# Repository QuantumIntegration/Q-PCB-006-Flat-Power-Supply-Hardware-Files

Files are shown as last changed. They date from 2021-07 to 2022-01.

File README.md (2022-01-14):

# Quantum DIY Kit Hardware Files - Flat Power Supply
## Introduction

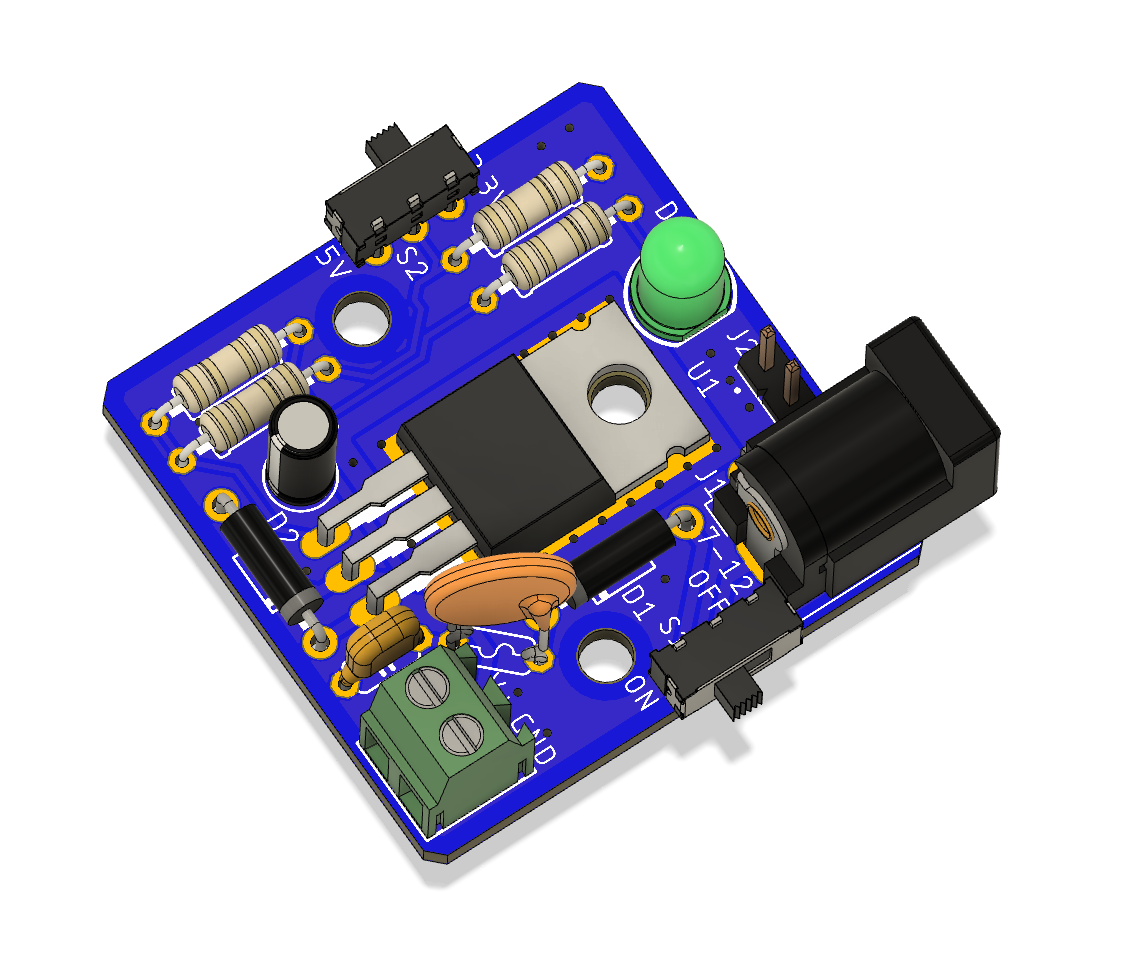
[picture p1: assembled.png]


This repository contains all the hardware files necessary to build the PCBs and assemble the DIY kits. The PCBs can be ordered from for example [JLCPCB](https://jlcpcb.com/) or [PCBWay](https://www.pcbway.com/). The components can be sourced mostly from [Amazon](https://amazon.com/) or [Digikey](https://digikey.com/), according to the links in the BOM file.

## Download the correct revision

If you are nor familiar with the git version control system, please follow these simple steps to download your version of the DIY kit

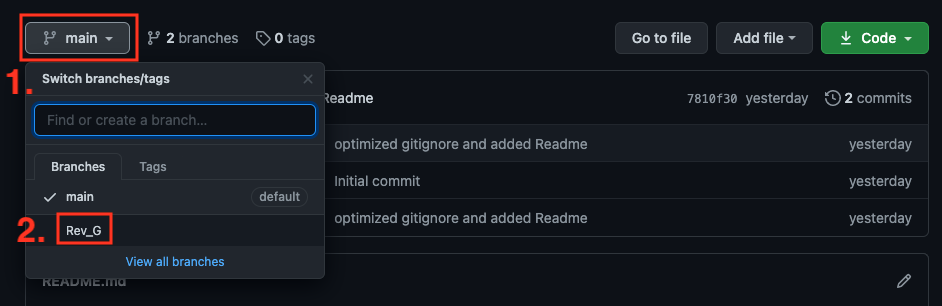
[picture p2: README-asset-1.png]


<em>1. Click the branch button</em>

<em>2. Select the branch matching your revision</em>

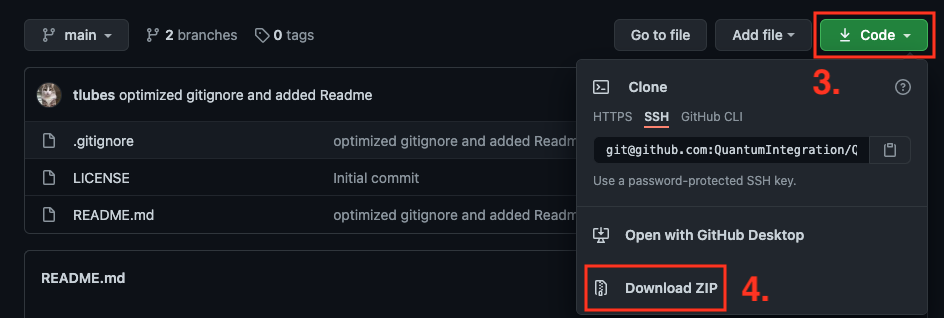
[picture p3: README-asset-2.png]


<em>3. Click the Code button</em>

<em>4. Download the ZIP and extract it on your machine</em>

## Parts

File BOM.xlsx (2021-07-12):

Index | Part | Value | Quantity | Designators | Package | Comments | Specific Part Reference | Part Link Example
1 | Terminal |  | 1 | J3 |  | 3.50mm, 1x2 |  | https://www.digikey.com/product-detail/en/w%C3%BCrth-elektronik/691214110002/732-2747-ND/2508516
2 | Barrell Jack |  | 1 | J1 |  | 2.1mm jack |  | https://www.digikey.com/products/en?keywords=694106301002
3 | Slide Switch |  | 2 | S1, S2 |  | 90 degree | EG1270 | https://www.digikey.com/product-detail/en/e-switch/EG1270/EG1847-ND/6076
4 | Ceramic Capacitor | 100n | 1 | C1 | 024x044 |  |  | https://www.digikey.com/product-detail/en/kemet/C315C104M5U5TA7303/399-9859-1-ND/3726100
5 | Electrolytic Capacitor | 1u | 1 | C2 | E2-4 | H: 8mm, 50V |  | https://www.digikey.com/product-detail/en/nichicon/USA1H010MDD1TE/493-14556-3-ND/4994224
6 | Diode | 1-N4001 | 2 | D1, D2 |  |  |  | https://www.digikey.com/product-detail/en/comchip-technology/1N4001-G/641-1310-3-ND/1979654
7 | Resistor | 240 | 1 | R1 | 0207/10 | 1/4 W |  | https://www.amazon.com/SIQUK-Resistors-Resistor-Assortment-Experiments/dp/B07PTNN78Z
8 | Resistor | 330 | 1 | R3 | 0207/10 | 1/4 W |  | https://www.amazon.com/SIQUK-Resistors-Resistor-Assortment-Experiments/dp/B07PTNN78Z
9 | Resistor | 390 | 1 | R2 | 0207/10 | 1/4 W |  | https://www.amazon.com/SIQUK-Resistors-Resistor-Assortment-Experiments/dp/B07PTNN78Z
10 | Resistor | 4.7k | 1 | R4 | 0207/10 | 1/4 W |  | https://www.amazon.com/SIQUK-Resistors-Resistor-Assortment-Experiments/dp/B07PTNN78Z
11 | PTC Fuse | 500m | 1 | F1 |  | self reset |  | https://www.amazon.com/gp/product/B00X774PAY/ref=ppx_yo_dt_b_asin_title_o03_s00?ie=UTF8&psc=1
12 | LED | green-diffused | 1 | D3 | 5mm |  |  | https://www.amazon.com/Diffused-Lighting-Electronics-Components-Emitting/dp/B01C3ZZU3G
13 | LM317 |  | 1 | U1 | TO-220-3 |  | LM317T | https://www.digikey.com/product-detail/en/stmicroelectronics/LM317T/497-1575-5-ND/591677
14 | Header |  | 1 | J2 | 0.1 | 1x2, male |  | https://www.amazon.com/MCIGICM-Header-2-45mm-Arduino-Connector/dp/B07PKKY8BX
15 | M3 Screw |  | 2 |  |  | 6mm |  | https://www.amazon.com/gp/product/B07CNF3W7B/ref=ppx_yo_dt_b_asin_title_o01_s00?ie=UTF8&psc=1
16 | Thermal Pad |  | 1 |  |  | fits LM317 |  | https://www.digikey.com/product-detail/en/bergquist/HF115AC-0-0055-AC-54/BER167-ND/307789
17 | Battery Harness |  | 1 |  |  | 2.1 mm plug |  | https://www.amazon.com/AKOAK-Battery-Button-Connector-Holder/dp/B01E9TXP7M

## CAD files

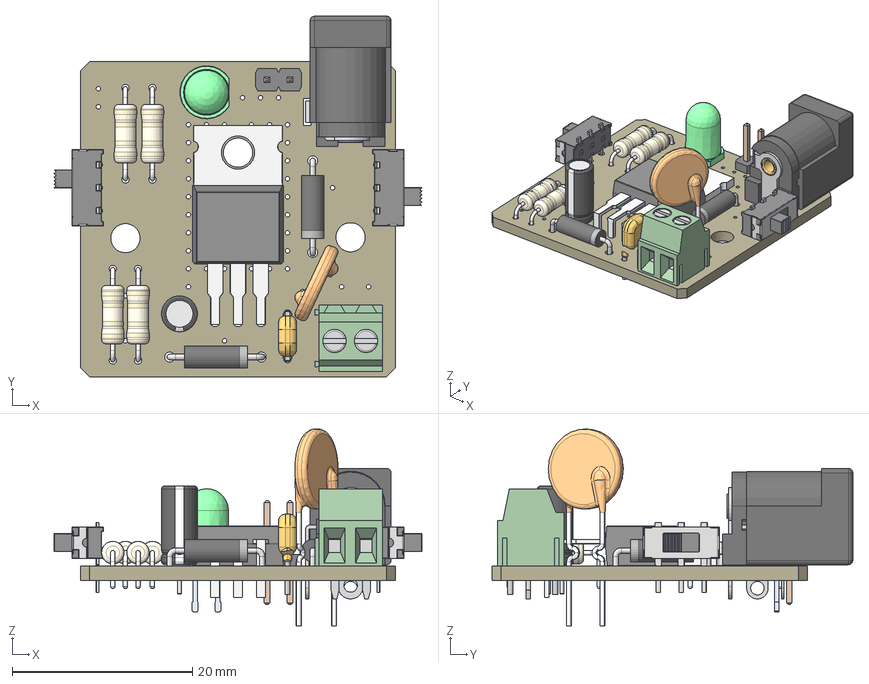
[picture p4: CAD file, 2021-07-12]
model.step
40.9 x 40.1 x 21.8 mm
Board
6941xx301002
694106301002_PinContact
6941xx301002_Back
6941xx301002_PinContact2
6941xx301002_PinLame
6941xx301002_PinBis
6130xx11121_PIN x 2
0207/10 x 4
C050-024X044
DO41-10 x 2
Pin
Seal
Can
Main_cover_black_10-10-10
Negative_cover
EG1270-90 x 2
LED5MM
PTC-FUSE
pin3
6912141100xx_CAGE x 2
6912141100xx_PIN x 2
6912141100xx_VIS x 2

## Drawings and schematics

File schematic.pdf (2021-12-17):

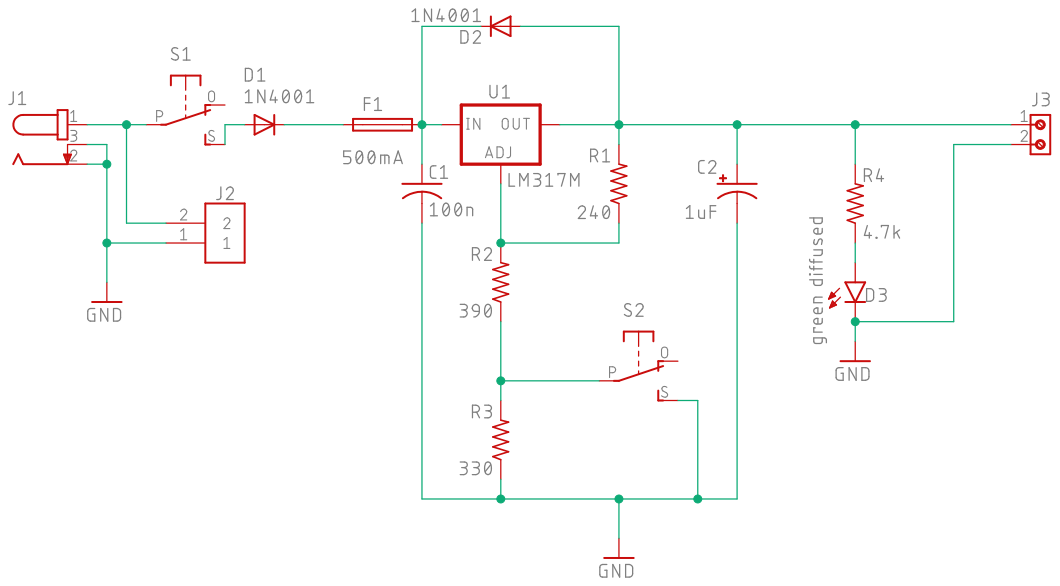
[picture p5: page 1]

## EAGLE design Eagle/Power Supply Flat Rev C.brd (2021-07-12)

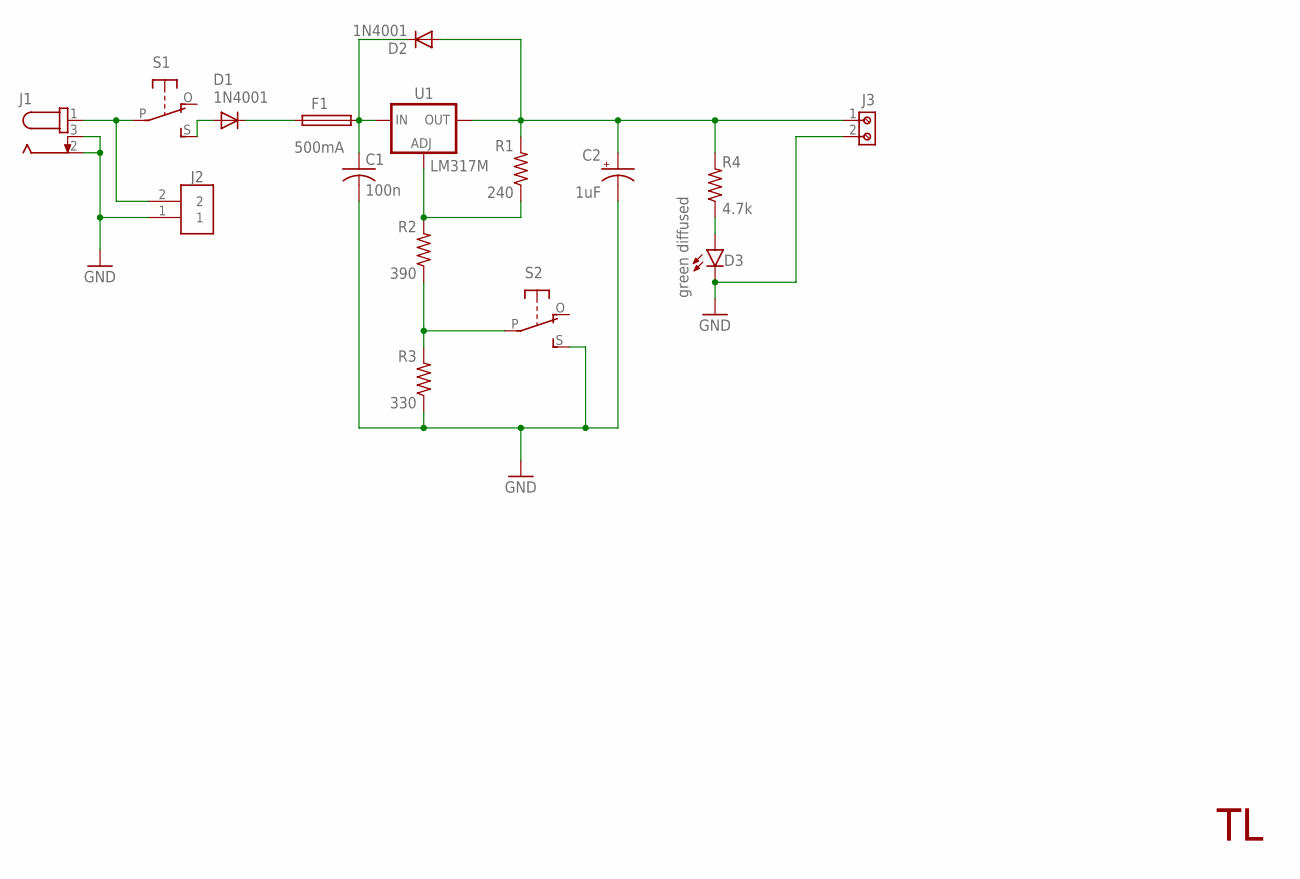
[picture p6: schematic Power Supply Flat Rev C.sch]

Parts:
C1: 100n; C050-024X044
C2: 1uF; E2-4
D1, D2: 1N4001; DO41-10
D3: green diffused; LED5MM
F1: 500mA; PTC-FUSE
J1: 694106301002
J2: 61300211121
J3: 691214110002
R1: 240; 0207/10
R2: 390; 0207/10
R3: 330; 0207/10
R4: 4.7k; 0207/10
S1, S2: SLIDE-SWITCHSIDE; EG1270-90
U1: LM317BENT; T03B; PARTNUMBER LM317M

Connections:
GND: C1.2, C2.-, D3.K (C), J1.2, J1.3, J2.1, J3.2, R3.1, S2.S
unnamed: D1.A, S1.S
unnamed: J1.1, J2.2, S1.P
unnamed: D1.C, F1.1
unnamed: C1.1, D2.C, F1.2, U1.3 (IN)
unnamed: R1.1, R2.2, U1.1 (ADJ)
unnamed: C2.+, D2.A, J3.1, R1.2, R4.2, U1.2 (OUT)
unnamed: R2.1, R3.2, S2.P
unnamed: D3.A, R4.1

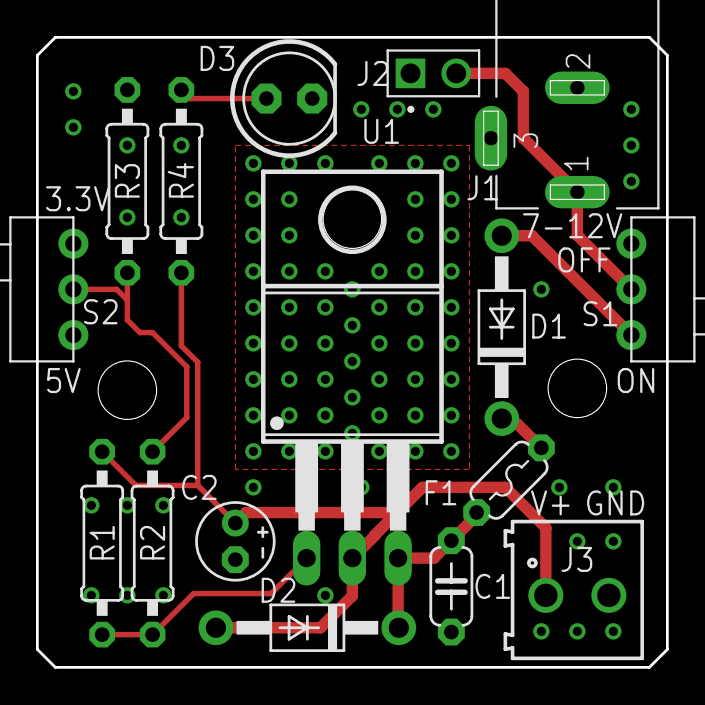
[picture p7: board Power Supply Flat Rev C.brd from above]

Board: 2 copper layers, 35.0 x 35.0 mm, 16 parts (0 on the bottom side), 9 nets.

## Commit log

2021-07-12 initial content
    [BOM.xlsx, Power Supply Flat Rev C.brd, Power Supply Flat Rev C.sch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]
2021-12-17 added schematic

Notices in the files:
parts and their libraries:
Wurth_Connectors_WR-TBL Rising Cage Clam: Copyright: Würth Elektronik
